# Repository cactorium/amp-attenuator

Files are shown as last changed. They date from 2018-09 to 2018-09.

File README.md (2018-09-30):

# 8 Ohm fixed level audio attenuator
This is a circuit to attenuate tube amp outputs to get power stage distortion at apartment-preferred levels.
Just stick between the amp and the 8 ohm speaker, and it'll attenuate the power by a fixed amount.
It's currently untested, but the boards should be ordered by the time this is published.
It should be safe to use for up to 10 W tube amps, and probably safe up to 20-25 W.
It's a simple T-pad attenuator, using one or two Yageo SQP10A (or equivalently sized) resistors for each of the three resistances.
Below is the BOM for various attenuation levels:

|Attenuation level|R1|R2|R3|R4|R5|R6|J1|J2|
|----|----|----|---|---|---|---|--|--|
|-3 dB|SQP10A-2R7|SQP10A-2R7|SQP10A-22R|DNP|SQP10A-2R7|SQP10A-2R7|NYS216|NYS216|
|-6 dB|SQP10A-2R7|DNP|SQP10A-22R|SQP10A-22R|SQP10A-2R7|DNP|NYS216|NYS216|
|-10 dB|SQP10A-4R7|DNP|SQP10A-5R6|DNP|SQP10A-4R7|DNP|NYS216|NYS216|
|-12 dB|SQP10A-4R7|DNP|SQP10A-8R2|SQP10A-8R2|SQP10A-4R7|DNP|NYS216|NYS216|

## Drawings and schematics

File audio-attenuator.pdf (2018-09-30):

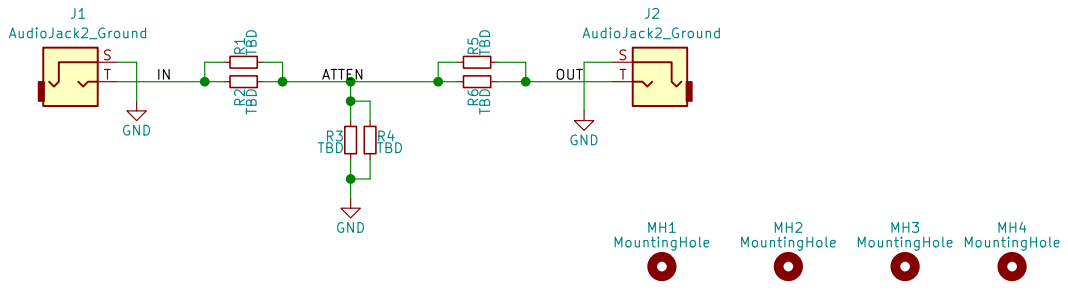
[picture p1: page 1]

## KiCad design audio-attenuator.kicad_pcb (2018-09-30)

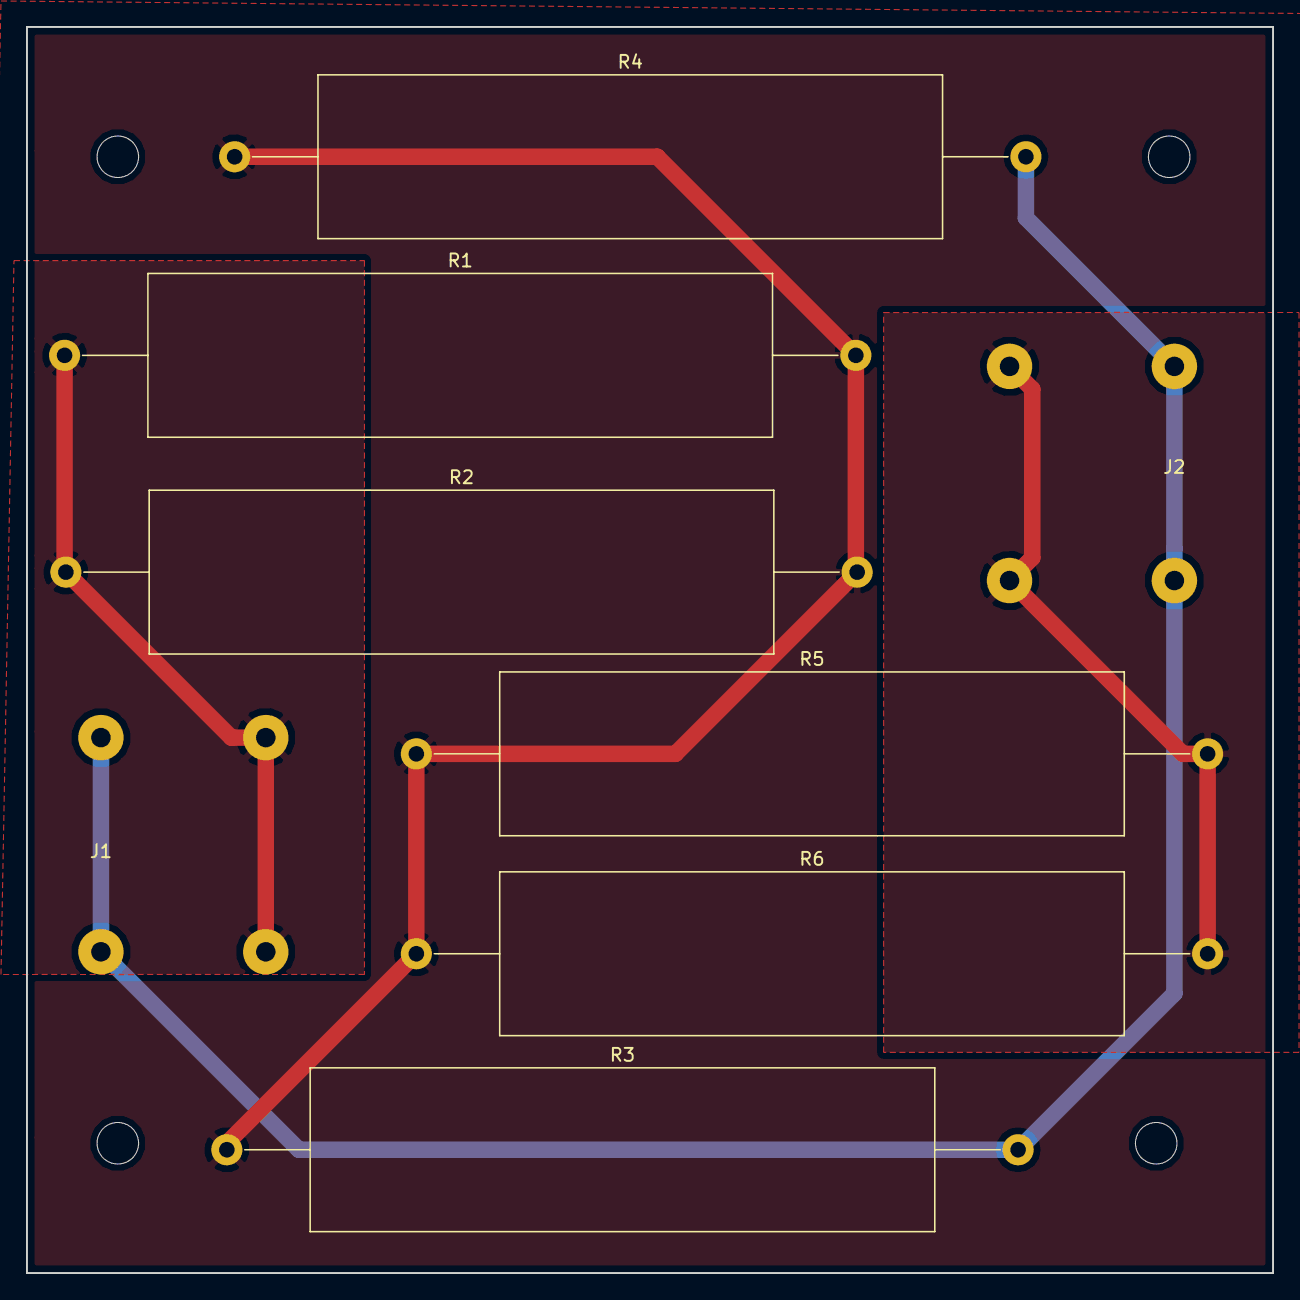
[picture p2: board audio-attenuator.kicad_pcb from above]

Board: 2 copper layers, 96.0 x 96.0 mm, 12 parts (0 on the bottom side), 4 nets.

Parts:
J1, J2: AudioJack2_Ground; NYS2162-U
MH1, MH2, MH3, MH4: MountingHole; MountingHole_3.2mm_M3
R1, R2, R3, R4, R5, R6: TBD; R_Axial_Power_L48.0mm_W12.5mm_P60.96mm

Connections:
/ATTEN: R1.2, R2.2, R3.1, R4.1, R5.1, R6.1
/IN: J1.T, R1.1, R2.1
/OUT: J2.T, R5.2, R6.2
GND: J1.S, J2.S, R3.2, R4.2

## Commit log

2018-09-30 First revision
    [audio-attenuator-B.Cu.gbl, audio-attenuator-B.Fab.gbr, audio-attenuator-B.Mask.gbs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]
2018-12-05 Zip Gerbers for sending to fab
